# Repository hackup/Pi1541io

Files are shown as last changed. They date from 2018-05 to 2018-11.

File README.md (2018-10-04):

# PI1541 IO Adapter

This is an IO adapter board for the Raspberry Pi 3, based on the awesome [Pi1541
project](https://cbm-pi1541.firebaseapp.com/) by Steve White. It is currently
very much work in progress. **USE AT YOUR OWN RISK!**

Details of the adapter board development are [documented on hackup.net](https://www.hackup.net/tag/pi1541/). The [Gerber files](gerber/Pi1541io-rev4.zip) for the latest stable revision are included in the repository. Also, the boards are ready to be ordered directly from [PCBWay](https://www.pcbway.com/project/shareproject/Pi1541_IO_Adapter__Rev_4.html?inviteid=78096) or [DirtyPCBs](https://dirtypcbs.com/store/designer/details/hackup/6112/pi1541-io-adapter-rev-4).

## Revisions

### Revision 4
This revision of the board resolves the I2C power supply issues of the previous version. All relevant aspects of the I2C header must now be configured using solder bridges on the bottom side of the PCB.

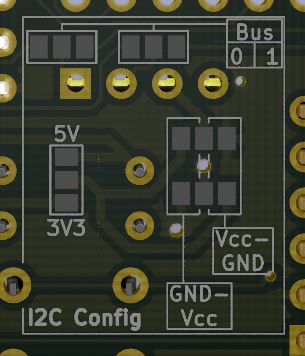
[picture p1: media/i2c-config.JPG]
I2C Configuration Jumpers


* Select either 3.3V or 5V power supply. (If in doubt, use 3.3V!)
* Pin order: Vin-GND-SCL-SDA or GND-Vin-SCL-SDA
* Chose either I2C bus 0 or 1

See [here](https://www.hackup.net/2018/07/pi1541io-revision-4/) for more details.

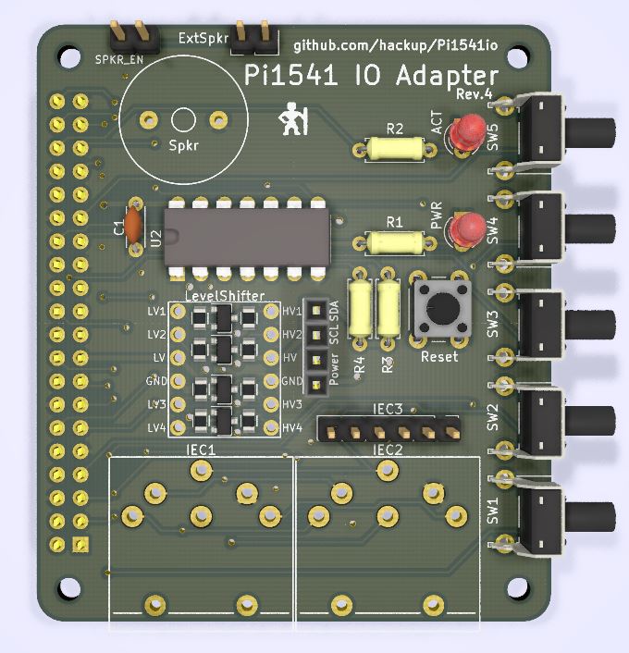
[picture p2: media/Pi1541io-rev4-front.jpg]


### Revision 3
The third revision features an I2C header for connecting a SSD1306 based OLED display module. The power line on this header is connected to 5V of the Raspberry. This is the preferred option for display modules that bring their own 3.3V regulator. Unfortunately, there seem to be modules out there without such a regulator. Connecting one of those to 5V will damage both the display and the Raspberry.

This issue is resolved in revision 4. So, unless you already have one of these boards you better skip directly to revision 4.

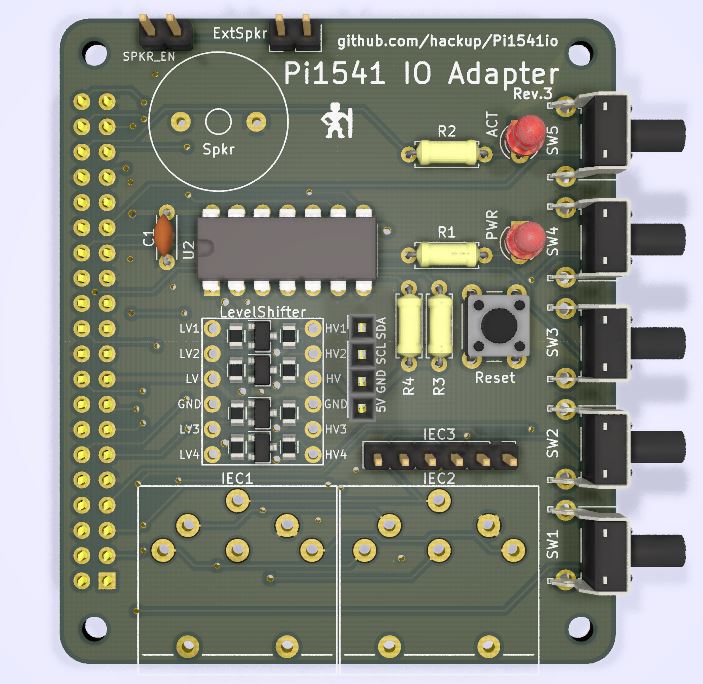
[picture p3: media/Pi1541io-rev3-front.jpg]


### Revision 2
The second revision features quite a few improvements, the most important one being optional support for the 7406 bus driver IC. For further details and instructions on how to assemble this board [see here](https://www.hackup.net/2018/06/pi1541io-revision-2/).

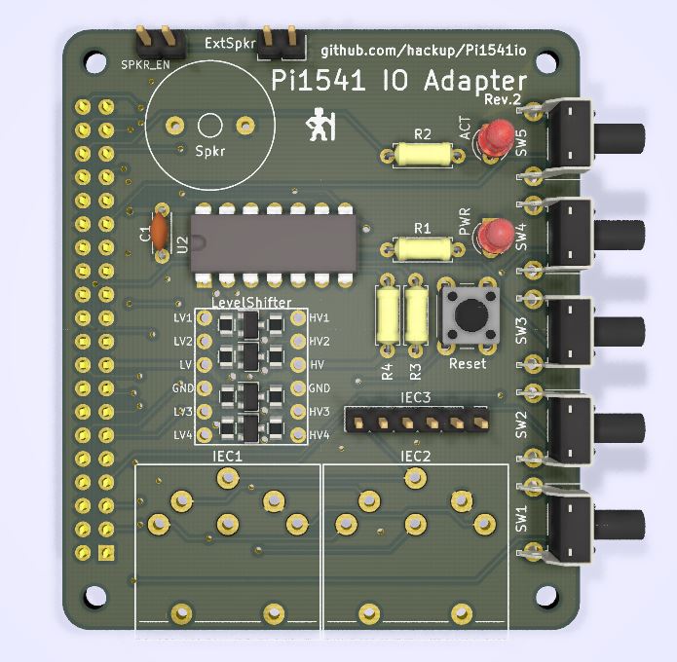
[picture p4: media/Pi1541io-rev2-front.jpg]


### Revision 1
A prototype batch of the first revision has been manufactured and [tested](https://www.hackup.net/2018/05/pi1541-io-adapter/). It is generally working but there are a few minor issues. The Gerber files for this revision are included, but I would currently recommend waiting for revision 2.

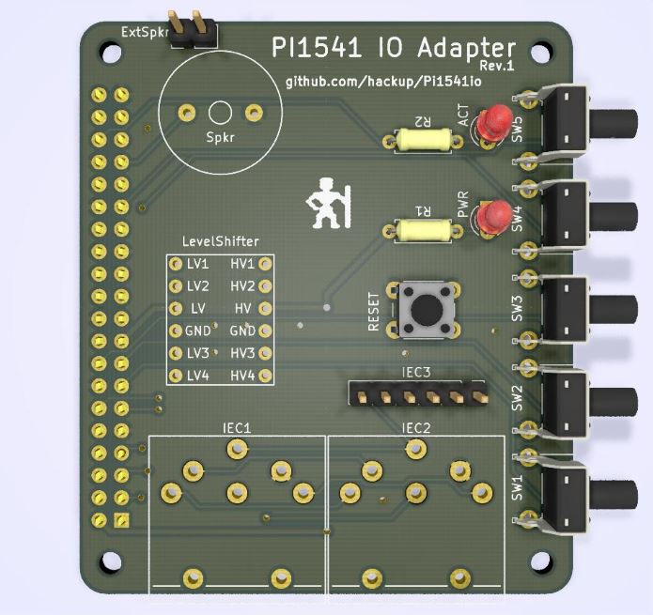
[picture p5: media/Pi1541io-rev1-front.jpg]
Pi1541io Rev.1


## License

This work is licensed under a
[Creative Commons Attribution-ShareAlike 4.0 International License](http://creativecommons.org/licenses/by-sa/4.0/)

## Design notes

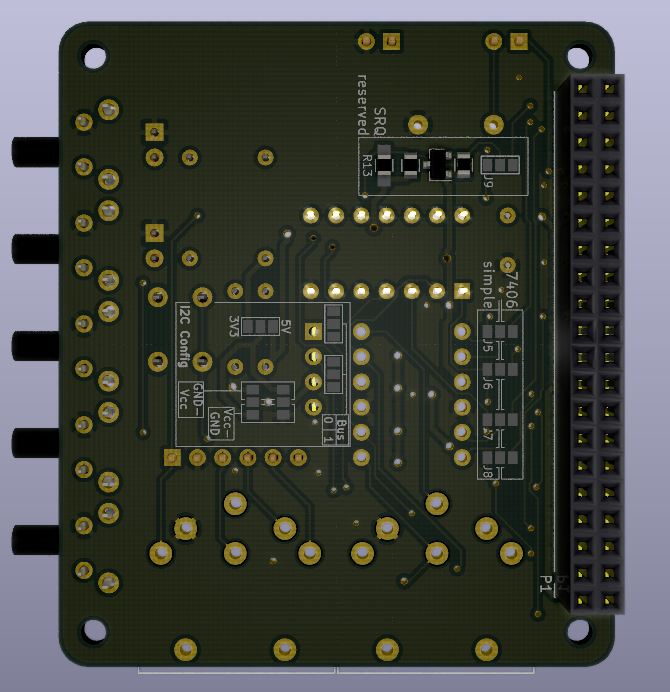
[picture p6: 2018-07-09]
media/Pi1541io-rev4-back.jpg

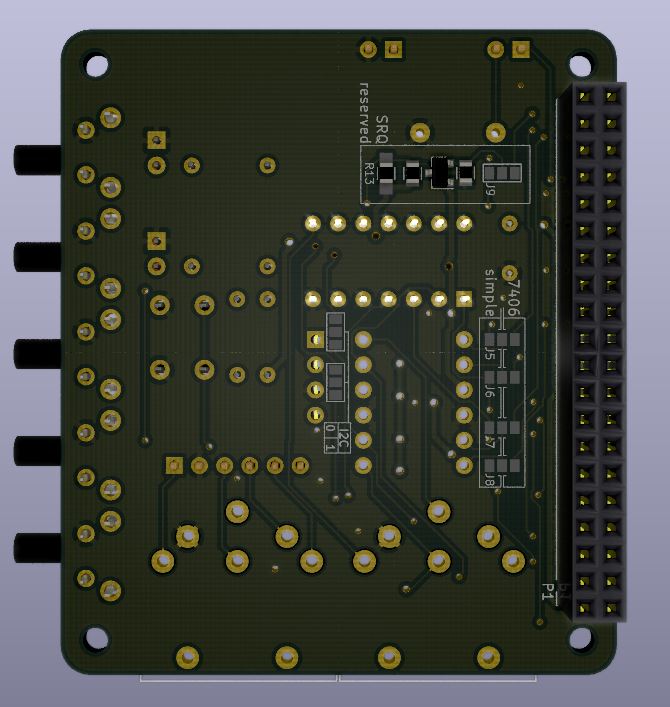
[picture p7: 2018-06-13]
media/Pi1541io-rev3-back.jpg

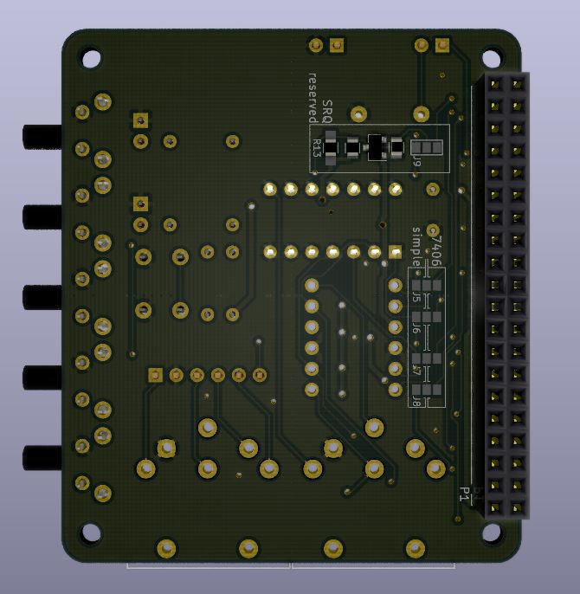
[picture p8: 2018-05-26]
media/Pi1541io-rev2-back.jpg

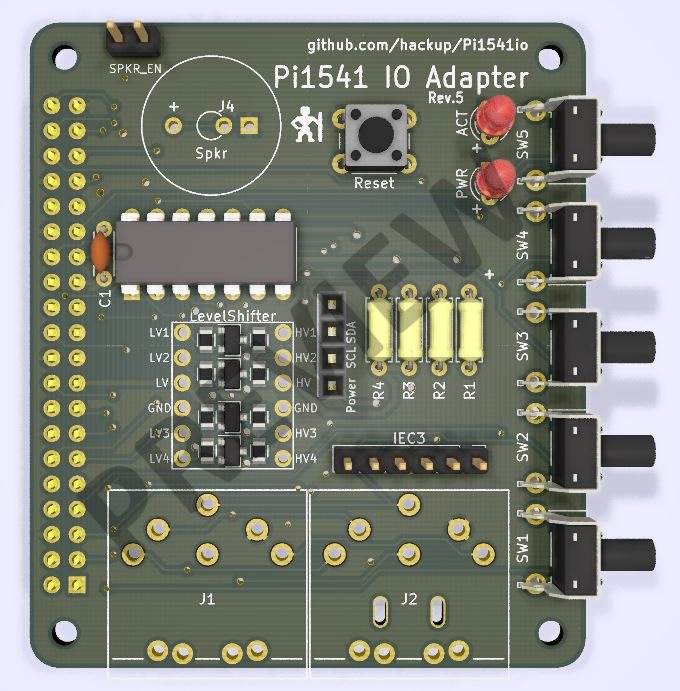
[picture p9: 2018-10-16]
media/Pi1541io-rev5-front.jpg

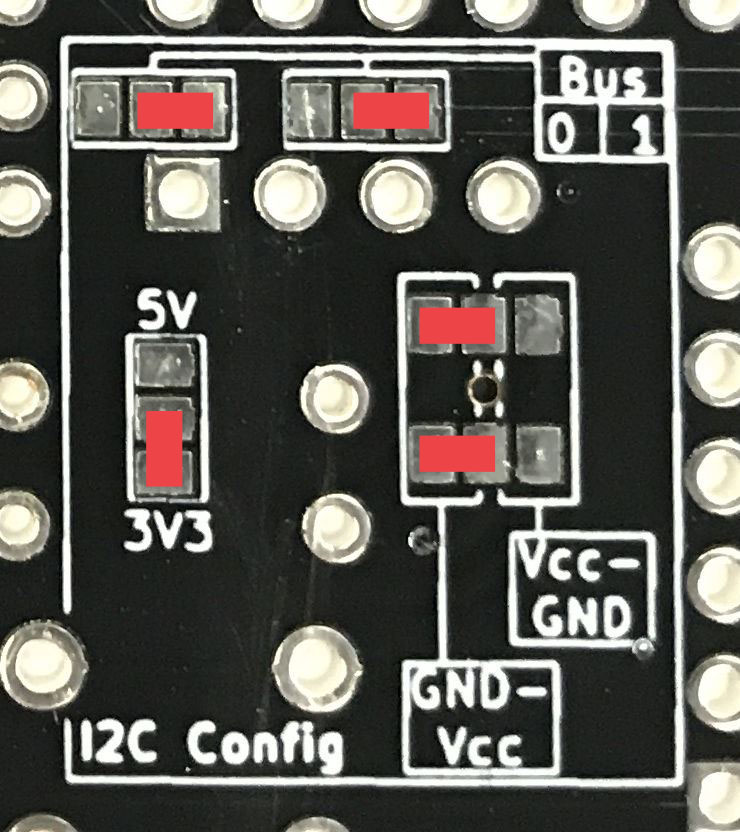
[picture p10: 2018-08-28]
media/i2c-config-example1.JPG

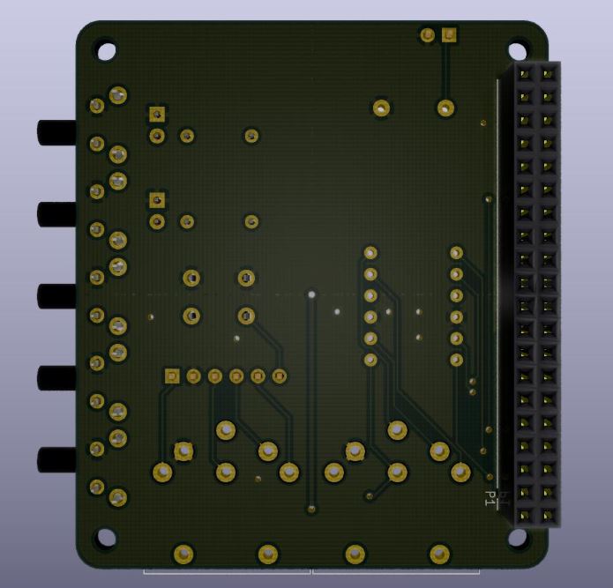
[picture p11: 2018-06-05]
media/Pi1541io-rev1-back.jpg

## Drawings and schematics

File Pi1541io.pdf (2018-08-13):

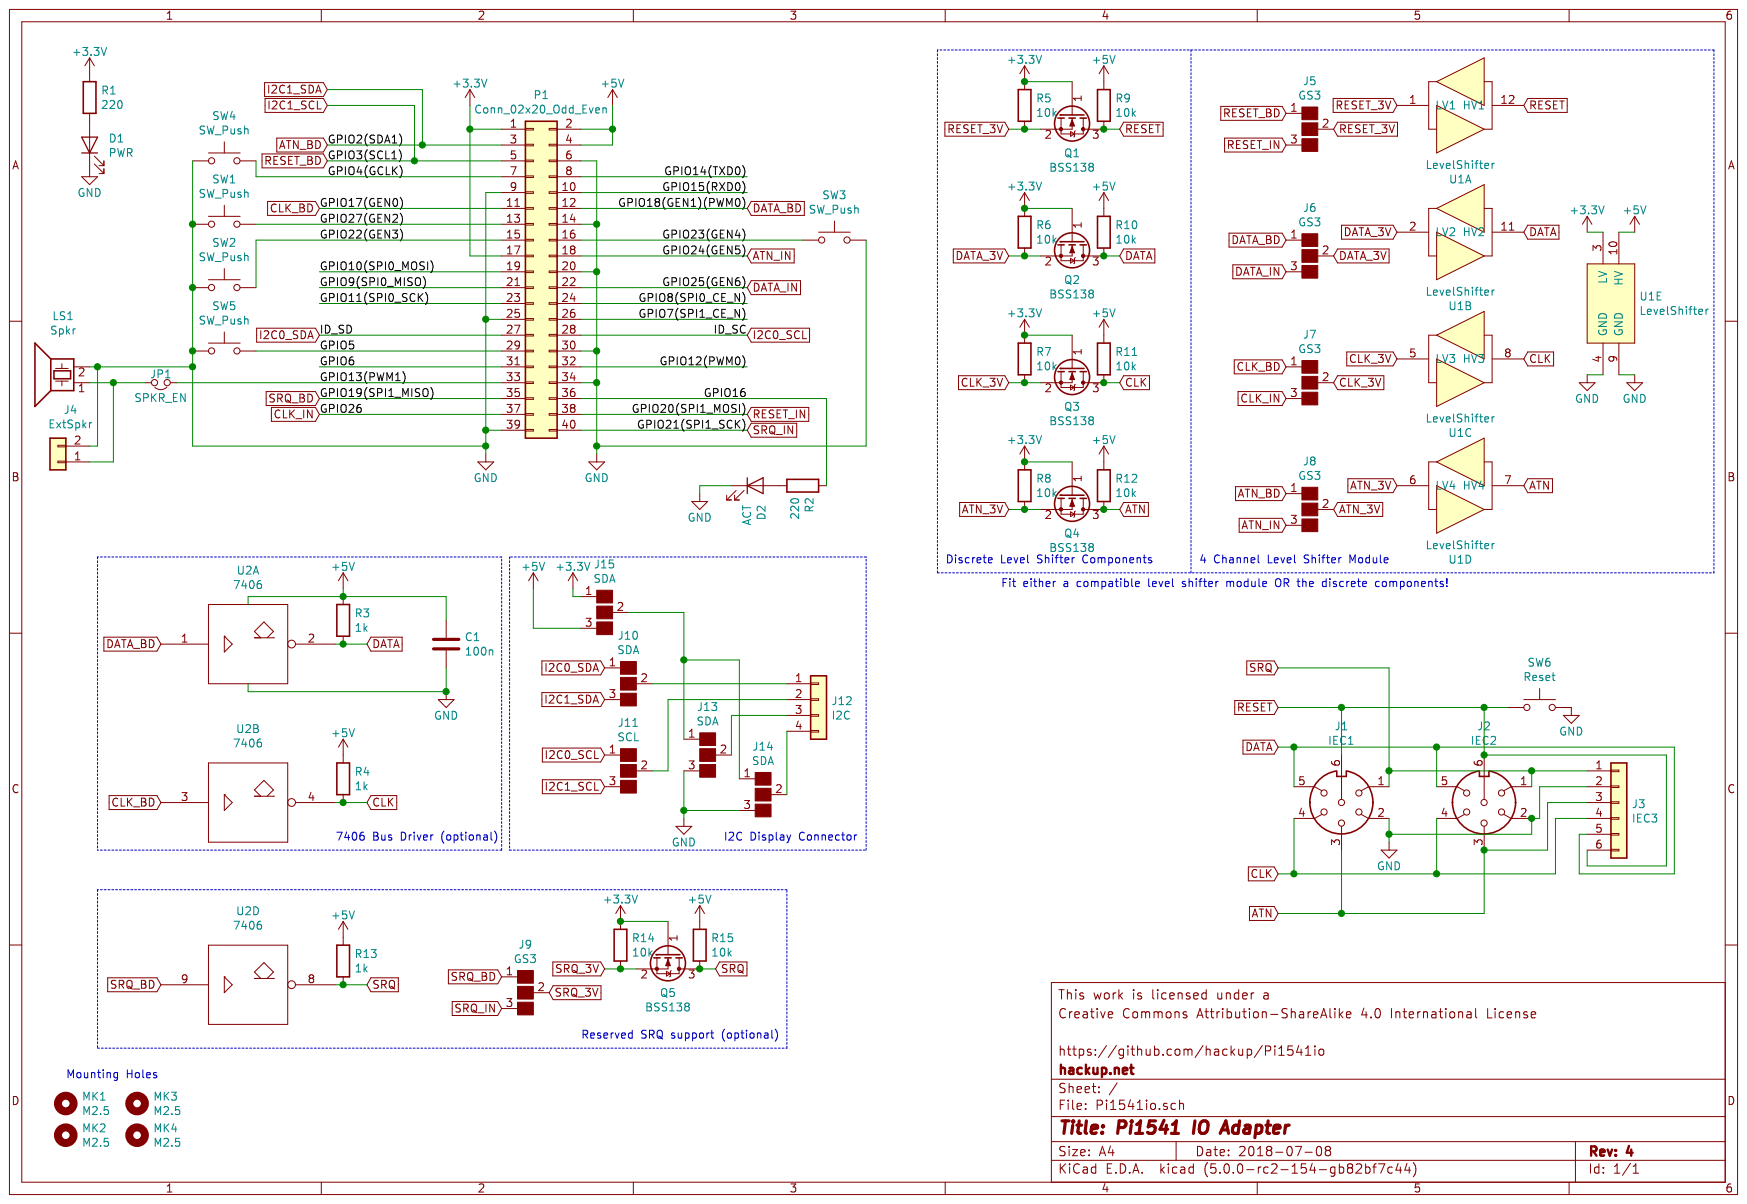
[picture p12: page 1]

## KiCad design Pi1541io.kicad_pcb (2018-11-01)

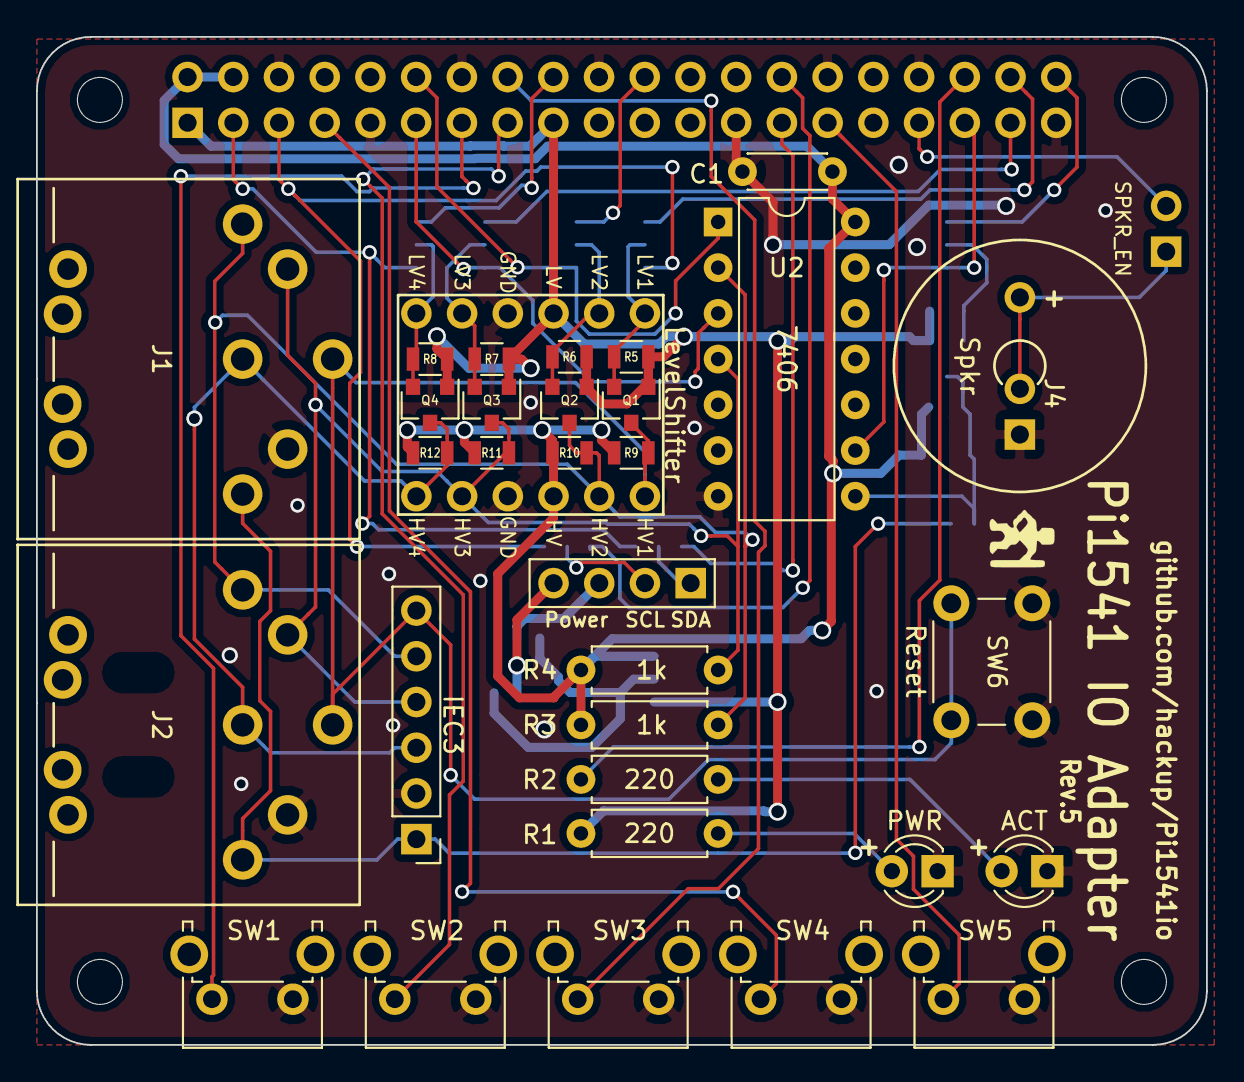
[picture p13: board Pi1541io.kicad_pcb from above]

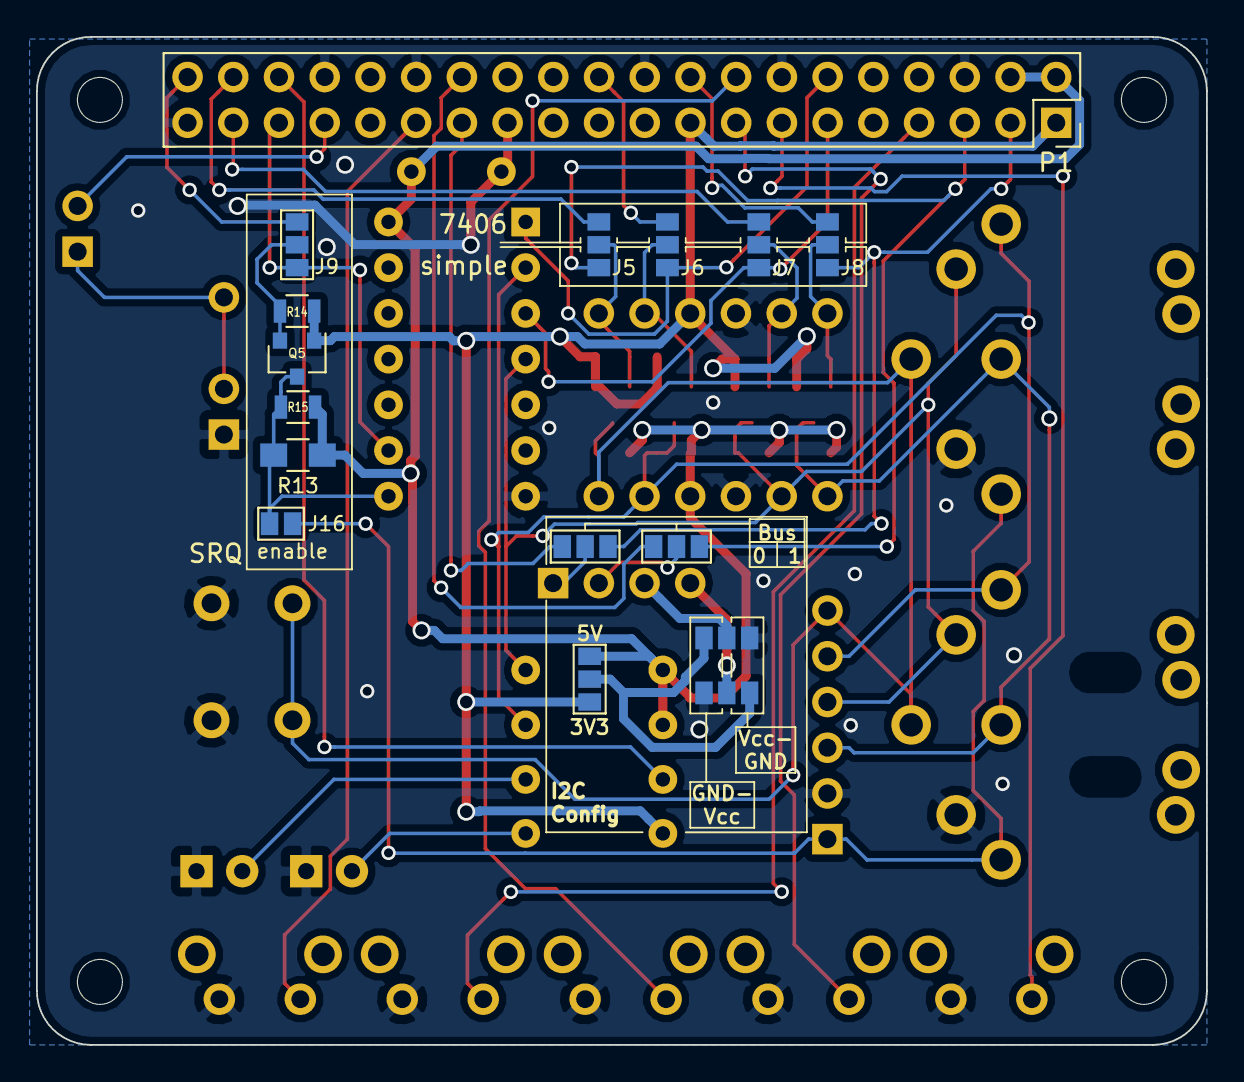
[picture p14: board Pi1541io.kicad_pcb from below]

Board: 2 copper layers, 65.0 x 56.0 mm, 56 parts (16 on the bottom side), 41 nets.

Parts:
C1: 100n; C_Disc_D4.3mm_W1.9mm_P5.00mm
D1: PWR; LED_D3.0mm
D2: ACT; LED_D3.0mm
J1: IEC1; DIN-6-Variable
J2: IEC2; DIN-6-Variable
J3: IEC3; Pin_Header_Straight_1x06_Pitch2.54mm
J4: ExtSpkr; Pin_Header_Straight_1x01_Pitch2.54mm
J5, J6, J7, J8, J9: GS3
J10, J13, J14, J15: SDA; GS3
J11: SCL; GS3
J12: I2C; Socket_Strip_Straight_1x04_Pitch2.54mm
J16: GS2
LS1: Spkr; Piezo Speaker 1407
MK1, MK2, MK3, MK4: M2.5; MountingHole_2.5mm
MK5, MK6: ZipTie; ZipTie_3.0mm
P1: Conn_02x20_Odd_Even; Socket_Strip_Straight_2x20_Pitch2.54mm
Q1, Q2, Q3, Q4, Q5: BSS138; SOT-23
R1, R2: 220; R_Axial_DIN0207_L6.3mm_D2.5mm_P7.62mm_Horizontal
R3, R4: 1k; R_Axial_DIN0207_L6.3mm_D2.5mm_P7.62mm_Horizontal
R5, R6, R7, R8, R9, R10, R11, R12, R14, R15: 10k; R_0805
R13: 1k; R_0805_HandSoldering
SW1, SW2, SW3, SW4, SW5: SW_Push; SW_Tactile_SPST_Angled_PTS645Vx83-2LFS
SW6: Reset; SW_PUSH_6mm
SW7: SPKR_EN; Pin_Header_Straight_2x01_Pitch2.54mm
U1: LevelShifter; LevelShifterModule4CH
U2: 7406; DIP-14_W7.62mm

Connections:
+3V3: J15.1, P1.1, P1.17, Q1.1, Q2.1, Q3.1, Q4.1, Q5.1, R1.1, R5.1, R6.1, R7.1, R8.1, R14.1, U1.3
+5V: C1.1, J15.3, P1.2, P1.4, R3.1, R4.1, R9.1, R10.1, R11.1, R12.1, R13.1, R15.1, U1.10, U2.14
/GPIO4(GCLK): P1.7, SW4.2
/GPIO5: P1.29, SW5.2
/GPIO13(PWM1): P1.33, SW7.2
/GPIO16: P1.36, R2.1
/GPIO22(GEN3): P1.15, SW2.2
/GPIO23(GEN4): P1.16, SW3.2
/GPIO27(GEN2): P1.13, SW1.2
ATN: J1.3, J2.3, J3.3, Q4.3, R12.2, U1.7
ATN_3V: J8.2, Q4.2, R8.2, U1.6
ATN_BD: J8.1, J10.3, P1.3
ATN_IN: J8.3, P1.18
CLK: J1.4, J2.4, J3.4, Q3.3, R4.2, R11.2, U1.8, U2.4
CLK_3V: J7.2, Q3.2, R7.2, U1.5
CLK_BD: J7.1, P1.11, U2.3
CLK_IN: J7.3, P1.37
DATA: J1.5, J2.5, J3.5, Q2.3, R3.2, R10.2, U1.11, U2.2
DATA_3V: J6.2, Q2.2, R6.2, U1.2
DATA_BD: J6.1, P1.12, U2.1
DATA_IN: J6.3, P1.22
GND: C1.2, D1.1, D2.1, J1.2, J2.2, J3.2, J13.3, J14.3, LS1.2, P1.6, P1.9, P1.14, P1.20, P1.25, P1.30, P1.34, P1.39, SW1.1, SW2.1, SW3.1, SW4.1, SW5.1, SW6.2, U1.4, U1.9, U2.7
I2C0_SCL: J11.1, P1.28
I2C0_SDA: J10.1, P1.27
I2C1_SCL: J5.1, J11.3, P1.5
unnamed: D1.2, R1.2
unnamed: D2.2, R2.2
unnamed: J4.1, LS1.1, SW7.1
unnamed: J10.2, J12.1
unnamed: J11.2, J12.2
unnamed: J12.3, J13.2
unnamed: J12.4, J14.2
unnamed: J13.1, J14.1, J15.2
unnamed: J16.2, Q5.3, R13.2, R15.2, U2.8
RESET: J1.6, J2.6, J3.6, Q1.3, R9.2, SW6.1, U1.12
RESET_3V: J5.2, Q1.2, R5.2, U1.1
RESET_IN: J5.3, P1.38
SRQ: J1.1, J2.1, J3.1, J16.1
SRQ_3V: J9.2, Q5.2, R14.2
SRQ_BD: J9.1, P1.35, U2.9
SRQ_IN: J9.3, P1.40

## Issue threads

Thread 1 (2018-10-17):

SRQ line makes datasette loading not working in latest pi1541 firmware

rainisto, 2018-10-17:
With the latest changes in pi1541 firmware (commit that introduced 1581 support) the behaviour of SRQ line has changed which causes noise (or something) to SRQ line that breaks the datasette loading.

Maybe add jumper to schematics that can be used to disconnect SRQ line from the 7406 pin8 to iec connector. So people could disconnect the line untill the burst mode support and SRQ changes are fixed in pi1541 firmware. Currently you have to cut the trace in order to get datasette loading working again.

Tested with V1.10 where datasette loaded programs fine vs v1.15 where datasette failed to load programs successfully. Steve is planning to look if there is a bug in burst mode code that might cause datasette to fail, so hopefully we also get firmware fix at some point.

hackup, 2018-10-18:
Thanks for the report. A way to disconnect the SRQ line from the 7406 sounds like a very reasonable idea to me and I will consider that for the next revision of the board. I might just add yet another solder bridge to the bottom side.

rainisto, 2018-10-24:
Latest commit in pi1541 has a fix: https://github.com/pi1541/Pi1541/commit/db692407c3a3afec76ae17b1bd42b1672cbd00cd

So issue goes away on next firmware version.

Closed 2020-06-15.

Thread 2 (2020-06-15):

If the version of KiCad used was documented, it'd make it easier to change

BigValen, 2020-06-15:
I was hoping to export out kicad_pcb file as a STEP file, to aid in making a case for it. However, there was a Great Renaming in KiCad, so attempts to do this with KiCad 5.1 or 5.0.2 result in:

Warning: 08:57:59: [3D File Resolver] No such path; ensure the environment var is defined
Warning: C:\Program Files\KiCad\share\kicad\modules\packages3d\\Socket_Strips.3dshapes\Socket_Strip_Straight_1x04_Pitch2.54mm.wrl
Warning: 08:57:59: C:/Jenkins/workspace/windows-kicad-msys2-stable/src/kicad/utils/kicad2step/pcb/oce_utils.cpp: AddComponent: 588
Warning: * no model defined for component 'J12'

Attempts to do this in KiCad 4.0.7 (last stable release) say "This model was created on a version of KiCad from 2017/11/30" - which isn't that useful, as there are no KiCad releases at that date.

Could you document which version of KiCad could read/change this project ?

hackup, 2020-06-15:
I haven't really worked on this project for about 2 years now and I'm afraid I can't tell you for certain. Looking at the schematics I exported, the last major revision (rev.4) of the project was done using version 5.0.0-rc2-154-gb82bf7c44.

Currently, I have version 5.1.5 installed and I did a quick check on a fresh clone of the project: I could read and change it just fine. "Only" the display of the 3D models seems indeed to be broken. But then, I never had 3D models for all of the components anyway, IIRC.

I agree it would be nice to fix this to a state where the 3D models are working again. I can't tell when I might find the time for that, though.

BigValen, 2020-06-15:
Frustrating that it's not a simple version issue. I'll see can I make it go by updating the individual components.

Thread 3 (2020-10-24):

Add 2 extra holes for Lumberg IEC connector

fruitCoder123, 2020-10-24:
When you make a new board revision maybe you can consider to add 2 extra holes (the ones most to the edge of the board) to fit also the Lumberg 0105 06 connector. The 2 pins of that connector are slightly more close to the center and therfor don't fit on the current revision 5 (and lower) boards.
As the connectors are somewhat hard to get Farnell is selling the Lumberg ones, here is a reference to the farnell page where you can also find the datasheet which holds exact info about the pinning layout:
https://nl.farnell.com/lumberg/0105-06/din-connector-rcpt-6pos-chassis/dp/2677786

Thanks for your effort! I hope you like my feedback/contribution. BR

hackup, 2020-10-24:
I think you might be mistaken. I actually added those two additional through-hole pads for the Lumberg connector in rev.5. I don't have any of those connectors though, so I never had the chance to verify the layout.
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

See also here:
https://www.pcbway.com/project/shareproject/Pi1541_IO_Adapter__Rev_5.html

fruitCoder123, 2020-10-30:
Allight! Somehow I took the files for version 4 as it seems, bummer! Maybe because at the main page version 5 is not mentioned..
Thanks for your effort, for now I had to snip off those 2 pins, I liked to use them as it provides a better mechanical connection but.. yeahhh...
Keep up the good work!

hackup, 2020-11-03:
Thanks! Fixed in ef5f29bfcea6542e7d95b61bb5cffca7b2ee1284.

Closed 2020-11-03.

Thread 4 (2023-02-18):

Newbie questions

faxm0dem, 2023-02-18:
Hi,

I just built my rev5 board and have a few questions, which are not necessarily all related to the io board.
Keep in mind I haven't hooked it to my C64 yet.

1. What cable should I use ? A straight DIN cable ?
2. My LCD displays the logo after power on, then nothing. On HDMI I just get this:
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
3. The buzzer doesn't make any sound
4. The reset button does nothing at all

hackup, 2023-02-18:
1. Use the same IEC cable that you would use to connect an original 1541 to the C64. That is indeed one with a 6-pin DIN-Connector on each end, all lines connected 1:1.
2. Have you copied the 1541 ROM image onto the SD card and named it properly as described on Steve's project page?
3. The buzzer should sound when the emulated drive is moving it's imaginary read/write head. You didn't get that far yet, if I understand correctly.
4. The reset button will reset the emulated 1541 drive once it is running.

I hope this is any help to you. Myself, I don't know the latest firmware versions of the Pi1541 project and cannot support those.

faxm0dem, 2023-02-19:
Thanks for your help !
2. Yes
4. But there is nothing visible on the LCD or hdmi when pushing the reset button ?

I managed to get further by using `IgnoreReset = 1` in `options.txt` as suggested on a video I found on youtube.
Now the LCD displays the list of files in the `1541` folder, and the HDMI too.
However, neither the keys on a USB keyboard or the buttons seem to do anything.

hackup, 2023-02-19:
If you changed directories or mounted a d64 image and press the reset button, both displays should return to showing what they displayed initially. Since you can't do this yet, I guess it is normal that the button doesn't seem to do anything. Also, I think that "IgnoreReset=1" will make the Pi1541 ignore resets...

I thought your issues might be caused by you Pi1541 not being connected to the IEC bus yet or by the 1.24 firmware version. So, I just downloaded and installed the latest kernel.img (I still was on 1.21 before), hooked up power, HDMI, and an USB keyboard to the Pi. Both the keyboard and the on board buttons are working in this setup.

I'll attach my own [options.txt](https://github.com/hackup/Pi1541io/files/10776669/options.txt) file here. It is based on an early version of the firmware so there will be parameters missing and relying on default values. But it is working for me with kernel.img 1.24 and might help you. Don't forget though, that you might need to change parameters like LCDName, SplitIECLines, InvertIECInputs, etc. to match your setup.

faxm0dem, 2023-02-19:
Thanks! I'll try your options asap

faxm0dem, 2023-03-12:
Hi, I eventually received the correct DIN connectors and soldered them to the board.
I also tried your `options.txt` and many other settings to no avail.

However, I just realised I didn't solder J5-J8 which config should I use ?

hackup, 2023-03-12:
Please see the description in my [blog post](https://www.hackup.net/2018/06/pi1541io-revision-2/) on how to configure J5-J8. Also, there is relevant information on the other jumpers to be found in the follow-up posts.

faxm0dem, 2023-03-12:
Thanks a bunch ! I did that and now it works !
Maybe I can thank you by adding something to the README : if you have this symptom, check J5-J8

Closed 2023-03-12.

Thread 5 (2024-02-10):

OLED display error

Banabas, 2024-02-10:
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
Hello.
First of all, thank you for the good project.
I have ordered io rev5 pcb's.
I now have a problem with the OLED display.
Something is cut off on the left and faded in again on the right.
The display should be OK.
Can you say something about it?

Greetings from DE

cgraefe, 2024-02-10:
Haven't seen this before, but I did a quick search on the web. Your display probably doesn't have an SSD1306 controller which, is the default for the Pi1541 firmware. Maybe your controller is an SH1106.  If I recall correctly, there is a configuration to enable to correct driver for this one. But the firmware is not my project, an I'm not expert on that topic.

Banabas, 2024-02-10:
OMG why didn't I think of that?
Sorry.
I actually thought I had chosen the right display.
Guess I didn't.
It works as it should now.
Thanks again.

hackup, 2024-02-10:
No problem. Glad to hear that you got it working now!

Closed 2024-02-10.

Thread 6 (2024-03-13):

Piezo Speaker

oXL0C0Xo, 2024-03-13:
I'm curious, does this need to be an active or passive speaker?

hackup, 2024-03-13:
It has to be a passive speaker! The firmware tries to modulate something that is supposed to resemble the sound of the stepper motor of the original drive. This will not work using an active speaker.

Closed 2024-03-13.

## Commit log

2018-05-09 Initial commit.
    [Pi1541io.kicad_pcb, Pi1541io.sch]
2018-05-09 Added speaker and activity LED.
    [Pi1541io.kicad_pcb, Pi1541io.sch]
2018-05-09 Meta data.
    [Pi1541io.kicad_pcb, Pi1541io.sch]
2018-05-09 Fixed page size.
    [Pi1541io.kicad_pcb]
2018-05-10 Added second IEC port and reset button.
    [Pi1541io.kicad_pcb, Pi1541io.sch]
2018-05-10 Added readme.
    [Pi1541io.kicad_pcb]
2018-05-10 Gerber export.
    [Pi1541io.kicad_pcb]
2018-05-18 Adding alternate TXS0108 level shifter module to choose from.
    [Pi1541io.sch]
2018-05-18 Reserved SRQ pin.
    [Pi1541io.kicad_pcb, Pi1541io.sch]
2018-05-23 Added 7406 driver for outgoing signals.
    [Pi1541io.kicad_pcb, Pi1541io.sch]
2018-05-24 Silk screen corrections. Re-added reset button.
    [Pi1541io.kicad_pcb, Pi1541io.sch]
2018-05-24 Discrete components to optionally replace the level shifter module.
    [Pi1541io.kicad_pcb, Pi1541io.sch]
2018-05-25 Added SRQ label.
    [Pi1541io.sch]
2018-05-25 Added optional components for reserved SRQ pins.
    [Pi1541io.kicad_pcb, Pi1541io.sch]
2018-05-25 Project spelling.
    [Pi1541io.kicad_pcb, Pi1541io.sch]
2018-05-25 Added missing values.
    [Pi1541io.kicad_pcb, Pi1541io.sch]
2018-05-25 Use wider footprint for cap.
    [Pi1541io.kicad_pcb, Pi1541io.sch]
2018-06-04 Commited rev.2 Gerber files.
2018-06-05 Added I2C display connector.
    [Pi1541io.kicad_pcb, Pi1541io.sch]
2018-06-12 Fine tuning I2C connector position.
    [Pi1541io.kicad_pcb]
2018-06-13 Updated page info.
    [Pi1541io.kicad_pcb, Pi1541io.sch]
2018-07-03 Kicad upgrade.
    [Pi1541io.sch]
2018-07-03 Use 3.3V instead of 5V on I2C header.
    [Pi1541io.kicad_pcb, Pi1541io.sch]
2018-07-05 Preparing revision 4.
    [Pi1541io.kicad_pcb, Pi1541io.sch]
2018-07-06 I2C power pins now configurable.
    [Pi1541io.kicad_pcb, Pi1541io.sch]
2018-07-08 Both voltage and pin order now configurable.
    [Pi1541io.kicad_pcb, Pi1541io.sch]
2018-08-13 Added current schematics as PDF document.
2018-08-28 Added I2C config example image.
2018-08-28 KiCAD 5.0.0.
    [Pi1541io.sch]
2018-08-28 Added HTML BOM export.
2018-09-04 Added additional drill holes for DIN connectors and polarity indicator for LEDs.
    [Pi1541io.kicad_pcb, Pi1541io.sch]
2018-09-21 Relocated reset button.
    [Pi1541io.kicad_pcb]
2018-09-21 Added ziptie holes.
    [Pi1541io.kicad_pcb, Pi1541io.sch]
2018-10-04 Added links to PCB fabs.
2018-10-05 Moved LEDs, texts, reset button, and speaker.
    [Pi1541io.kicad_pcb, Pi1541io.sch]
2018-10-05 Marked LED anodes.
    [Pi1541io.kicad_pcb]
2018-10-08 Improved ziptie holes.
    [Pi1541io.kicad_pcb, Pi1541io.sch]
2018-10-16 Shuffling layout to move the display connector.
    [Pi1541io.kicad_pcb]
2018-10-18 Added an additional solder bridge that is now needed to connect the SRQ line from the bus. This closes #1.
    [Pi1541io.kicad_pcb, Pi1541io.sch]
2018-10-18 Added footprint.
2018-10-18 Optimized silk screen.
    [Pi1541io.kicad_pcb]
2018-11-01 Fine tuning.
    [Pi1541io.kicad_pcb]
2018-11-01 Ready for next revision.
    [Pi1541io.kicad_pcb, Pi1541io.sch]
